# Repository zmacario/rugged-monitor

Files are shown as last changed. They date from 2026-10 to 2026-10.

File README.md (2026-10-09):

# Rugged Monitor EP-0084

A rugged, 3D-printed enclosure for the
[52Pi EP-0084](https://wiki.52pi.com/index.php/EP-0084) 7" capacitive touch display
(1024×600, HDMI, touch over USB).

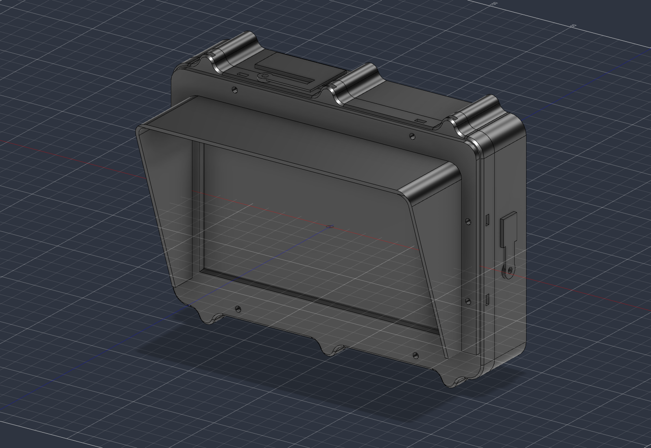
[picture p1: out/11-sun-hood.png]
Front with the sun hood

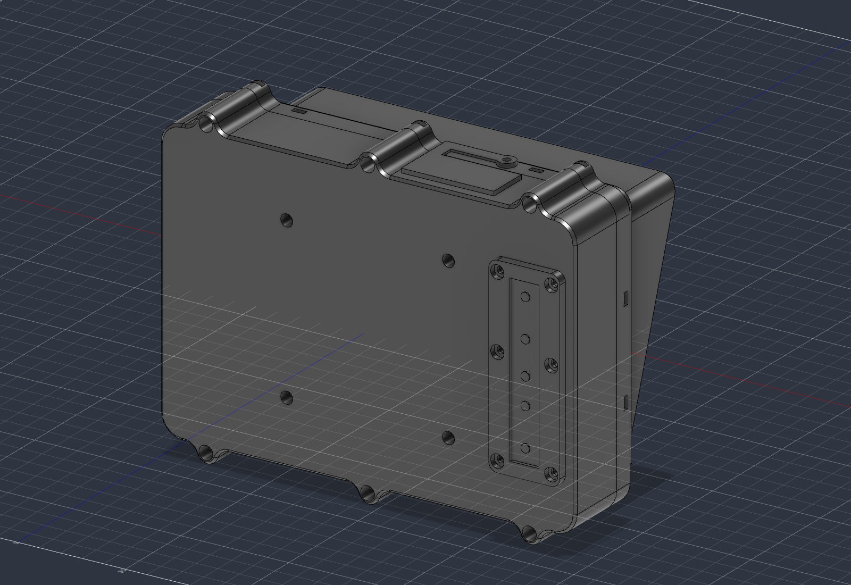
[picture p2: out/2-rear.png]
Rear


- Outer dimensions: 192.9 × 148.9 × 40.5 mm
- VESA 75 mount
- Protection against shock, dust and splashes (gasket between bezel and cover, caps on the ports)
- HDMI and power on the top edge, touch micro-USB on the side
- Menu buttons reachable from outside, through TPU keys
- Detachable sun hood, for use on a car dashboard
- Tilting desk stand, 0° to 60° back from vertical (see [Desk stand](#desk-stand))

## Parts

The files in `out/` open in print orientation and need no supports.

| File | Material | Volume |
|---|---|---|
| `front-bezel.stl` | Rigid | 90 cm³ |
| `chassis.stl` | Rigid | 46 cm³ |
| `rear-cover.stl` | Rigid | 184 cm³ |
| `keypad-frame.stl` | Rigid | 7 cm³ |
| `sun-hood.stl` | Rigid | 42 cm³ |
| `keypad-strip-tpu.stl` | TPU 95A | 2 cm³ |
| `port-cap-hdmi-dc-tpu.stl` | TPU 95A | 4 cm³ |
| `port-cap-usb-tpu.stl` | TPU 95A | 1 cm³ |

Rigid material: ASA for use in a car (PETG softens near 80 °C and PLA is not
suitable); PETG is enough for indoor use.

Fit tests, to validate clearances before printing the large parts:
`test-lcd-pocket.stl` (LCD pocket), `test-hardware.stl` (nut slots and holes) and
`test-port-walls.stl` (the port walls of the cover).

`rugged-monitor.step` holds the full assembly, including the kit components as
reference.

## Hardware

| Qty | Part | Where |
|---|---|---|
| 6 | M3×20 screw, socket cap head (DIN 912) | Closing the cover against the bezel |
| 5 | M3×16 screw, button head (ISO 7380) | Key pins |
| 31 | M3×10 screw, button head (ISO 7380) | Chassis (9), boards (6), keypad frame (6), sun hood (6), OSD keypad (2), port cap tethers (2) |
| 29 | M3 hex nut, standard (DIN 934) | Closure (6), chassis (9), boards (6), sun hood (8) |
| 10 | M3 heat-set threaded insert | Keypad frame (6), OSD keypad (2), port cap tethers (2) |
| 4 | M4 heat-set threaded insert | VESA mount |
| 4 | M4×8 screw | VESA mount |
| — | Neutral-cure silicone sealant | Gasket between bezel and cover |
| — | 1 mm adhesive foam tape | Between the front lip and the glass; between the LCD and the chassis |

No screw threads directly into plastic: nuts are held captive in slots where there
is access, and brass inserts are used in the blind holes that must not go through
the wall.

## Assembly, in short

1. Slide the 9 chassis nuts into the slots in the wall of the LCD pocket.
2. Stick the foam on the lip and lay the LCD + glass assembly in, with the flex cables on the side of the stops.
3. Fit the 6 nuts under the chassis, pass the flex cables through its slots and screw the chassis down.
4. Mount the video board and the touch board on the chassis and connect the flex cables.
5. On the cover: set the inserts, drop in the key pins, mount the OSD keypad, the keypad strip and the frame.
6. Close the cover with the 6 M3×20 screws.

The gasket is formed in place: silicone in the bezel groove, release agent on the
cover tongue, cured with the case closed and empty.

## Desk stand

A printed stand to use the monitor on a table. It bolts to the VESA 75 pattern of the
cover, so the enclosure itself is not modified, and the screen tilts from upright to
60° back.

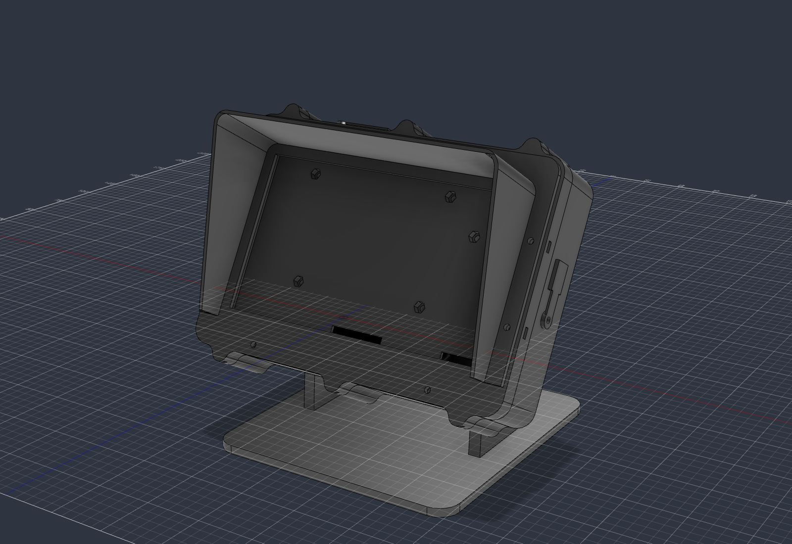
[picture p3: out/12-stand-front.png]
Desk stand, tilted 30°

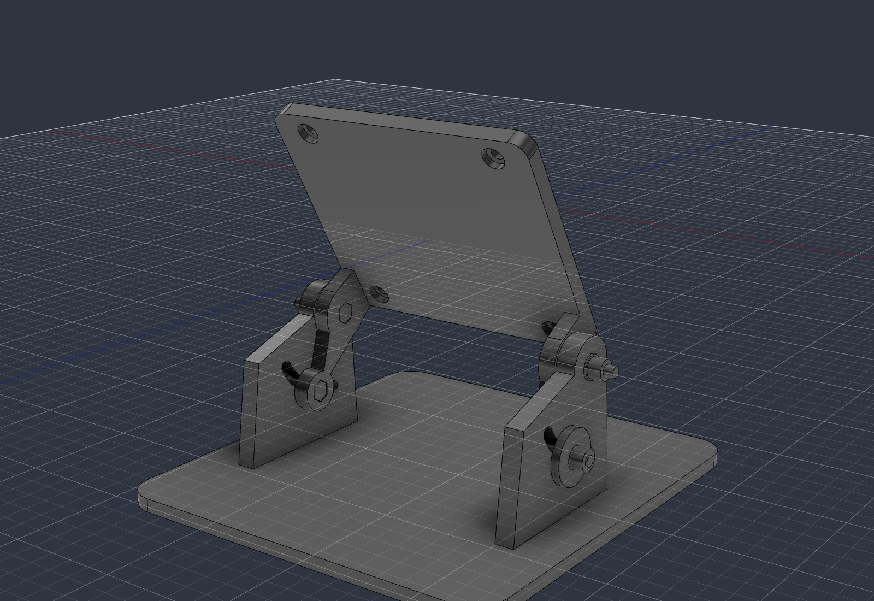
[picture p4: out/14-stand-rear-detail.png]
Stand from behind


- Footprint 150 × 160 mm; the lowest edge of the enclosure is 11 mm above the table
  when upright
- Two printed parts, no supports: a base with two arms, and a bracket (VESA plate with
  two side walls) that turns between the arms
- One M4 bolt per side is the pivot. A second one runs in an arc slot of the arm; a
  wing nut clamps the wall against the arm to hold the angle, so the tilt is
  continuous
- The sun hood fits at every angle; the stand does not cover the ports, the closure
  screws or the keys
- Self-adhesive rubber feet go in the four recesses under the base

| File | Material | Volume |
|---|---|---|
| `stand-base.stl` | Rigid | 153 cm³ |
| `stand-bracket.stl` | Rigid | 62 cm³ |
| `test-stand-hinge.stl` | Rigid | 28 cm³ |

`test-stand-hinge.stl` is a fit test: one arm with its slot and one wall with the
hex pockets and the counterbored VESA hole. Print it before the two large parts.
`desk-stand.step` holds the assembly, with the enclosure tilted 30° as reference.

| Qty | Part | Where |
|---|---|---|
| 4 | M4×8 screw, button head (ISO 7380) | Bracket to the VESA inserts of the cover |
| 4 | M4×20 bolt, hex head (DIN 933) | Pivot (2) and tilt lock (2); the head sits in a hex pocket of the wall |
| 2 | M4 nylon lock nut (DIN 985) | Pivot |
| 2 | M4 wing nut (DIN 315) | Tilt lock |
| 4 | M4 washer, 9 mm outside diameter | Under the nuts |
| 4 | Self-adhesive rubber foot, Ø10 mm | Underside of the base |

Assembly, in short:

1. Screw the bracket to the four VESA inserts of the cover; the screw heads sit in the counterbores.
2. Stand the base up and lower the bracket between its two arms.
3. On each side, push a bolt from inside the bracket through the wall and the arm, with the head in the hex pocket.
4. Pivot: washer and lock nut, tightened until the bracket turns freely without play.
5. Lock: washer and wing nut. Loosen to tilt, tighten to hold.

The two walls sit inside the arms, with 0.6 mm between wall and arm until the wing nut
is tightened.

## Regenerating the model

The model is generated by the `fusion/RuggedMonitor/RuggedMonitor.py` script, for
Autodesk Fusion. Every dimension lives in the `P` dictionary at the top of the file.

1. Copy (or link) the `fusion/RuggedMonitor` folder into Fusion's scripts folder.
2. In Fusion: Utilities → Scripts and Add-Ins → RuggedMonitor → Run.

The script rebuilds the "Rugged Monitor" document if it is open (otherwise it creates
a new one) and writes the STL files, the STEP file and the images to `out/`.

The stand is generated the same way by `fusion/RuggedMonitorStand/RuggedMonitorStand.py`
(link the `fusion/RuggedMonitorStand` folder too). It takes the enclosure from
`RuggedMonitor.py`, so both folders must be in the repository layout. Besides the parts
it moves the enclosure through the whole tilt range and logs any overlap and the
closest approach to the base in `out/build-stand.log`.

## Status

The bezel, chassis and cover have been printed and validated against the real
hardware. The keys (TPU strip, pins and frame), the port caps and the silicone gasket
have not been tested yet.

The desk stand has been checked in the model only (no overlaps from 0° to 60°, hardware
included). It has not been printed yet.

## License

- **The Fusion scripts** (`fusion/RuggedMonitor`, `fusion/RuggedMonitorStand`) — [MIT](LICENSE)
- **The design** (`out/*.step`, `out/*.stl`, renders) — [CC BY-SA 4.0](LICENSE-DESIGN.md)

You may print and sell this enclosure and its stand; credit José Macário (@zmacario), link back here,
and share modifications of the design under the same license. See
[LICENSE-DESIGN.md](LICENSE-DESIGN.md).

Not affiliated with 52Pi.

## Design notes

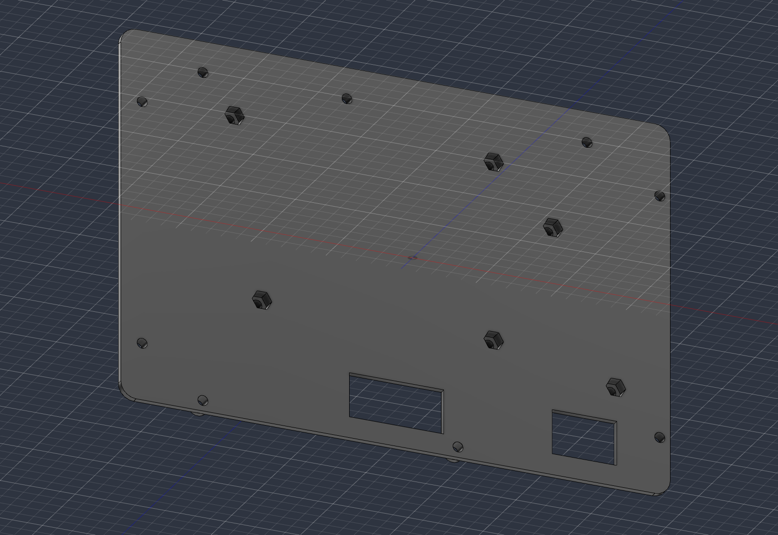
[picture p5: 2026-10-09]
out/10-chassis-underside.png

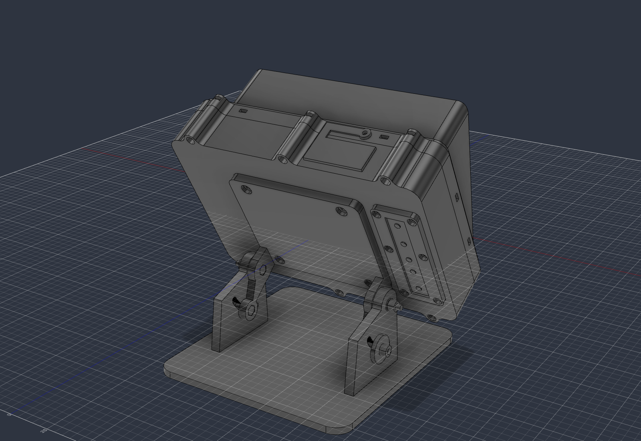
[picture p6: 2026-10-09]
out/13-stand-rear.png

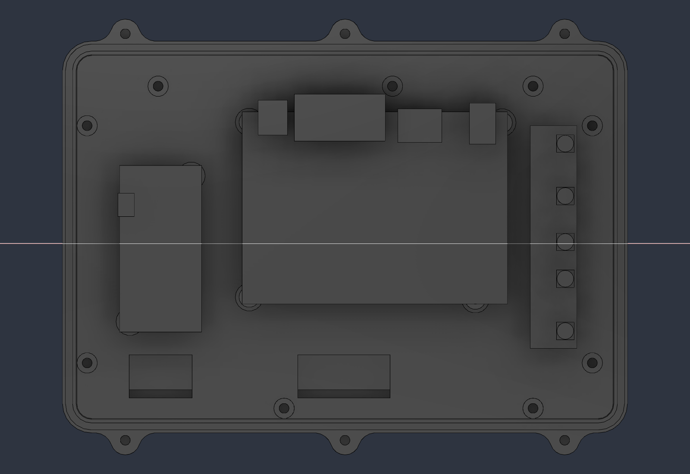
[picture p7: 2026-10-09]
out/4-interior-top.png

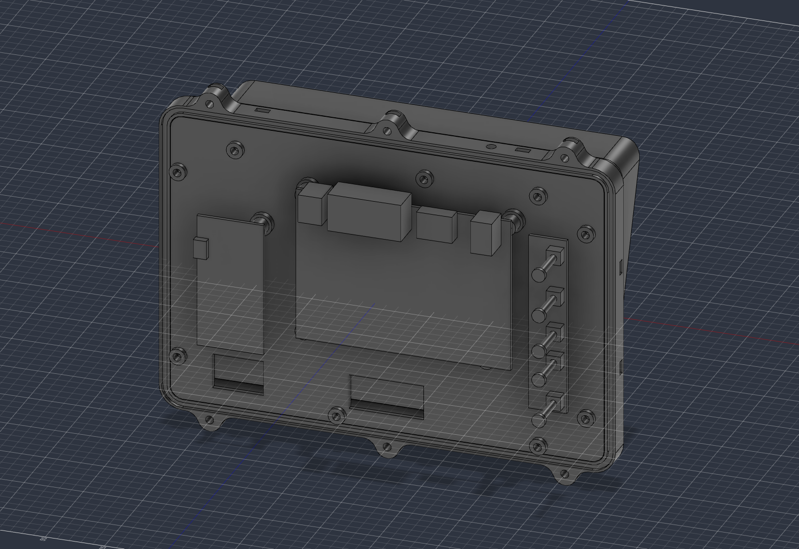
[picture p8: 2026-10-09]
out/3-interior.png

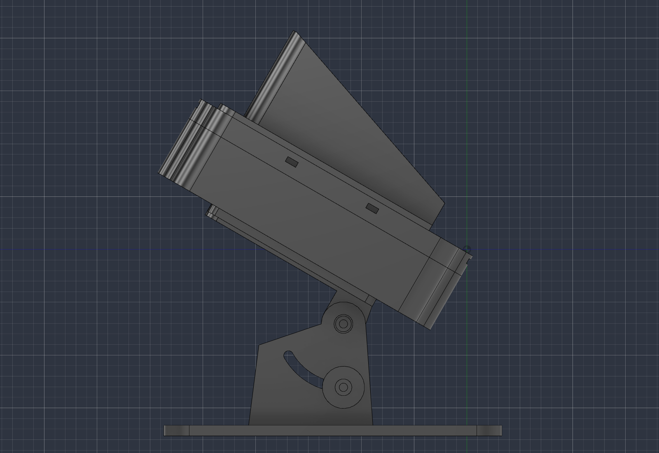
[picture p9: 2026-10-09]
out/15-stand-side-60.png

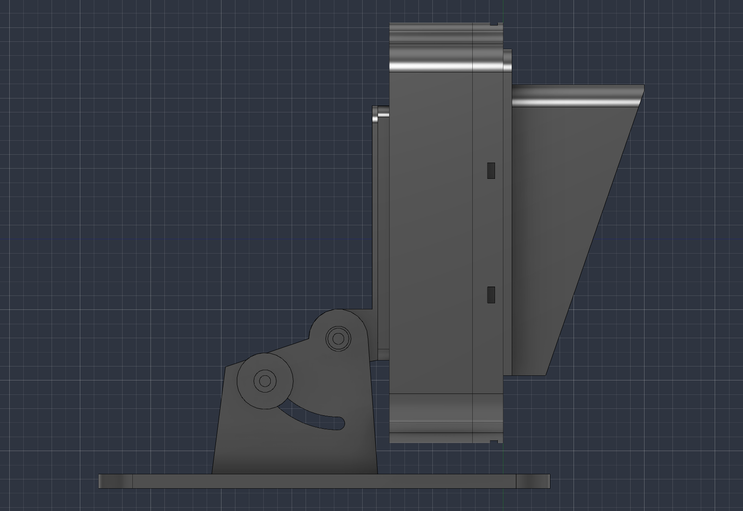
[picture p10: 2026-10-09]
out/15-stand-side-0.png

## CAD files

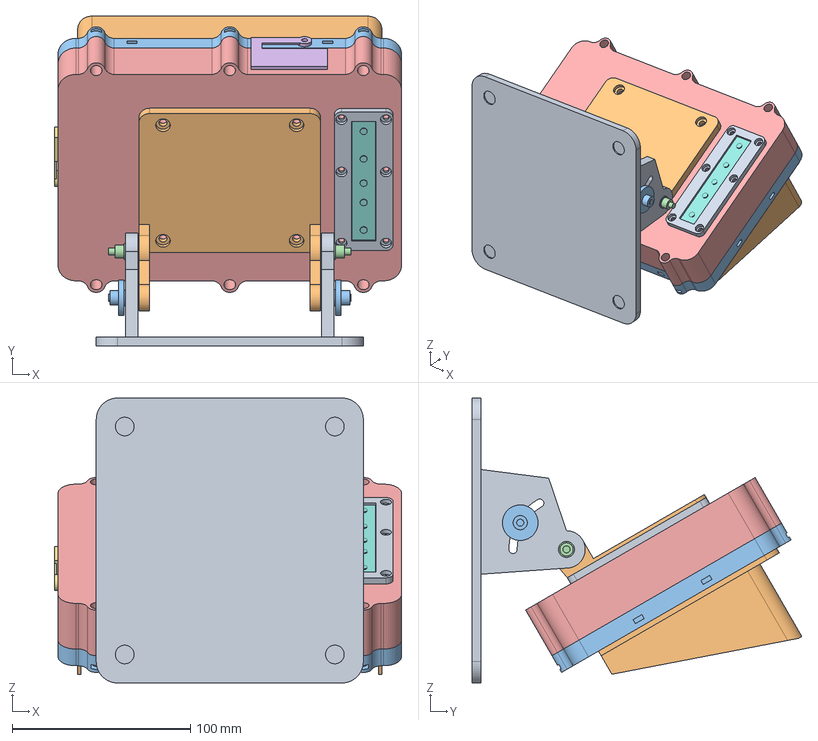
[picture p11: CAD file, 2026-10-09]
out/desk-stand.step
194.9 x 185.2 x 160.0 mm

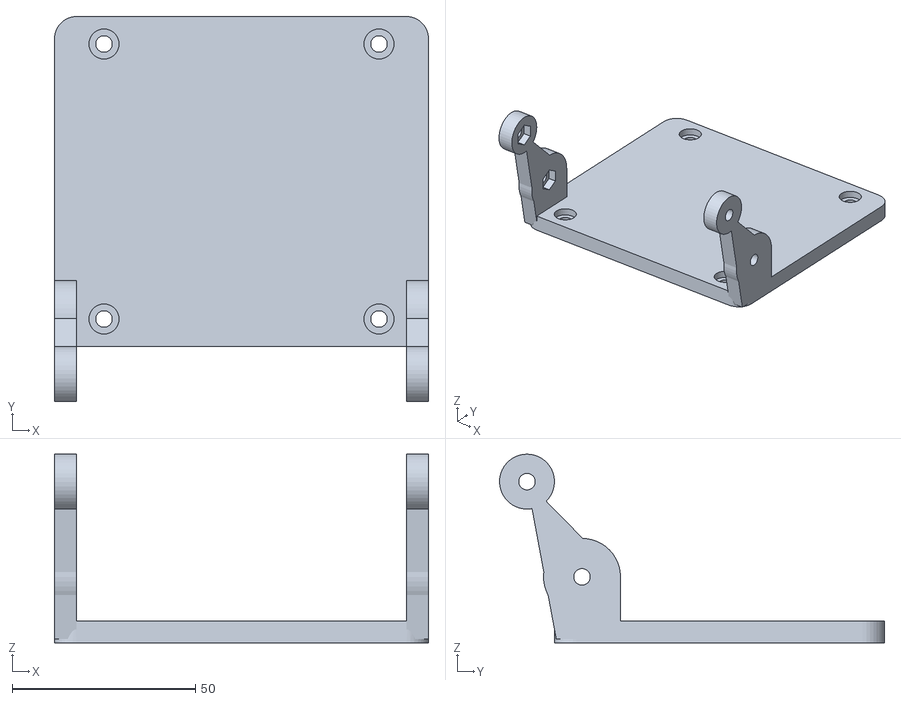
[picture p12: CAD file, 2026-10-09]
out/stand-bracket.stl
102.0 x 105.0 x 51.5

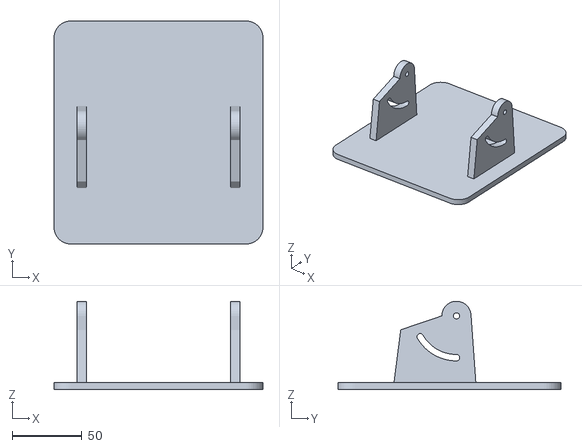
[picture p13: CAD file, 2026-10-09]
out/stand-base.stl
150.0 x 160.0 x 63.5

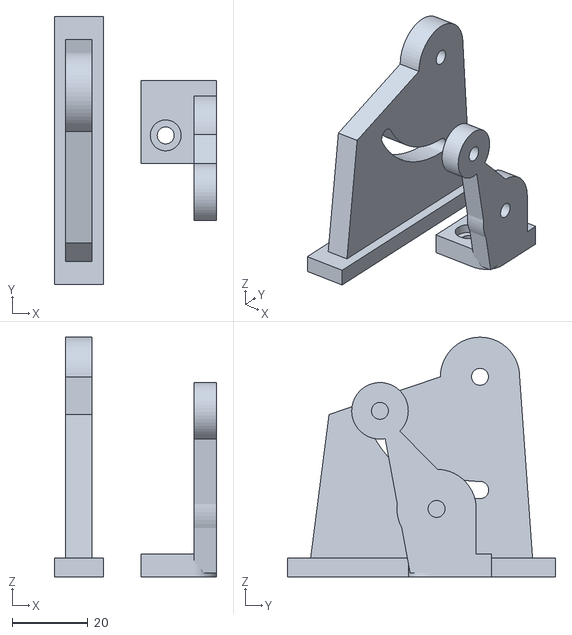
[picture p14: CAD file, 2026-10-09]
out/test-stand-hinge.stl
43.0 x 71.0 x 63.5

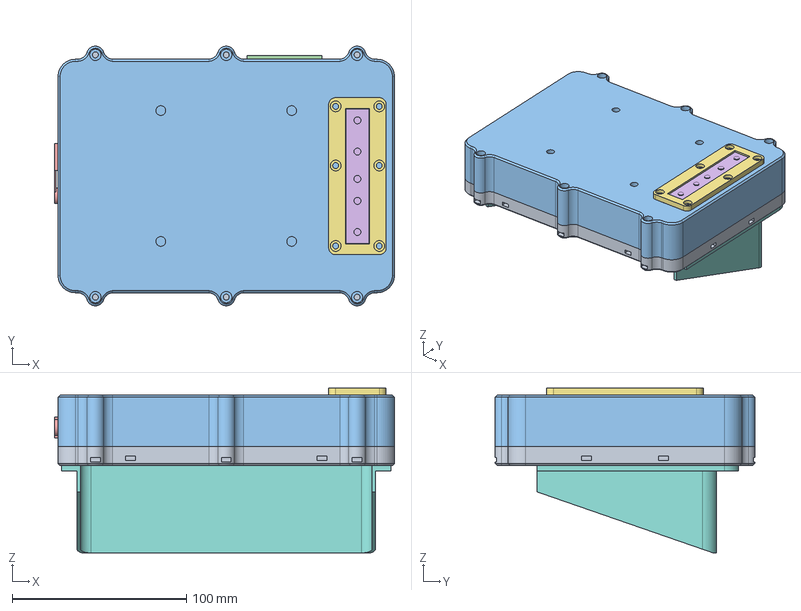
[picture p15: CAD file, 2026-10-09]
out/rugged-monitor.step
194.9 x 148.9 x 94.5 mm

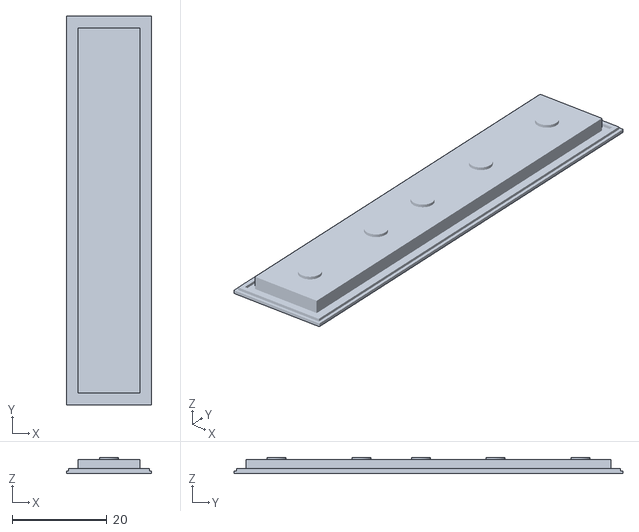
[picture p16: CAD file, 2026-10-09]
out/keypad-strip-tpu.stl
18.0 x 82.0 x 3.45

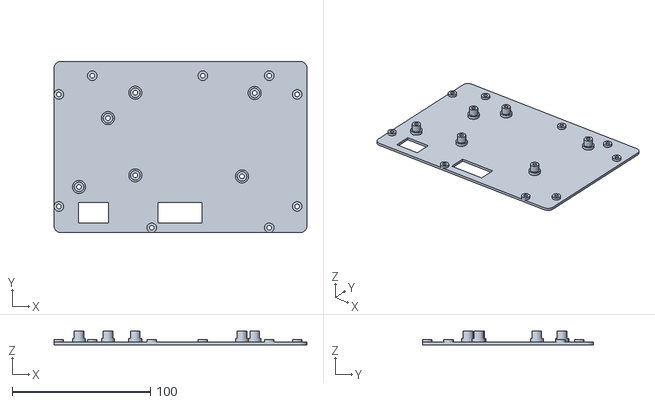
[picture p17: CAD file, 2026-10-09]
out/chassis.stl
183.1 x 124.1 x 10.0

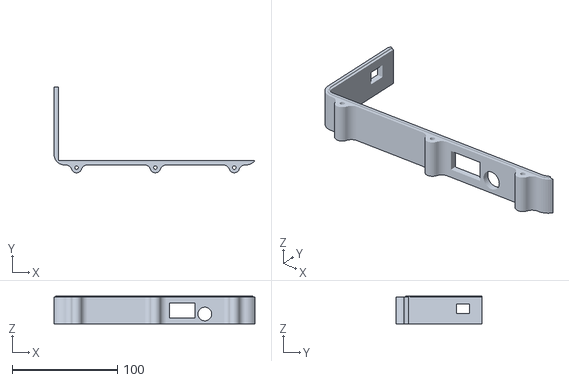
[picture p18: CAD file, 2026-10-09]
out/test-port-walls.stl
191.1 x 81.4 x 26.6

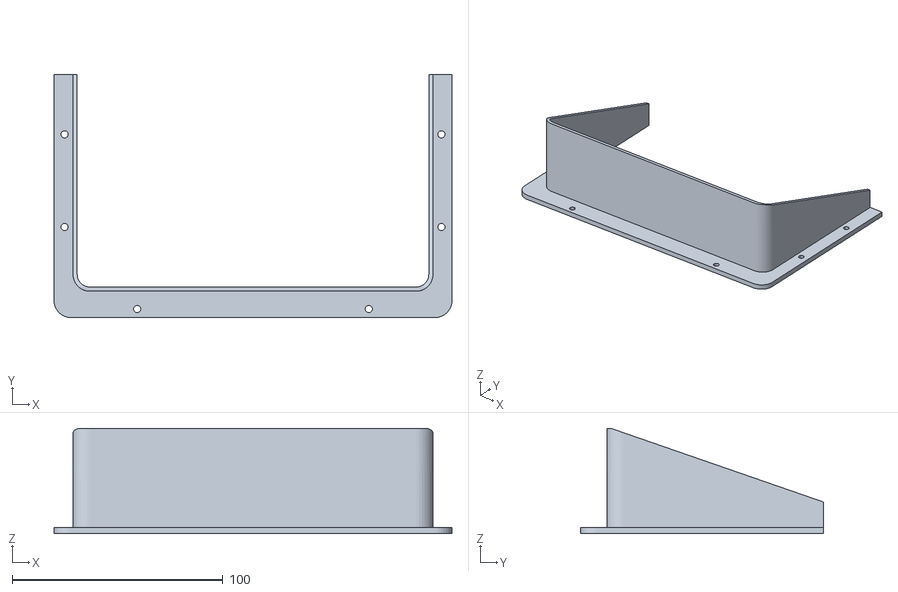
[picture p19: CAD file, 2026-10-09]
out/sun-hood.stl
189.1 x 115.5 x 50.0

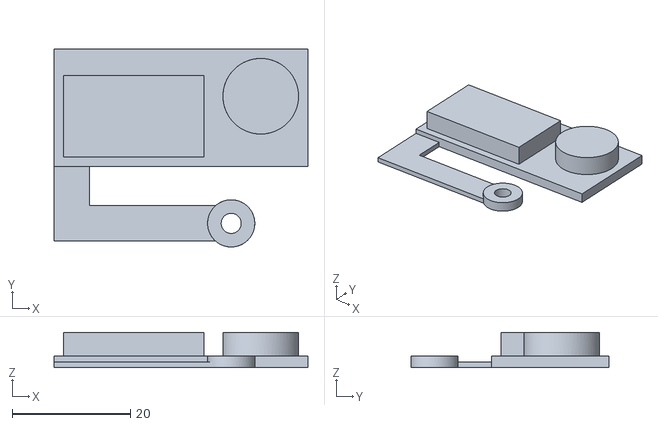
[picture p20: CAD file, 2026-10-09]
out/port-cap-hdmi-dc-tpu.stl
43.0 x 33.5 x 6.00

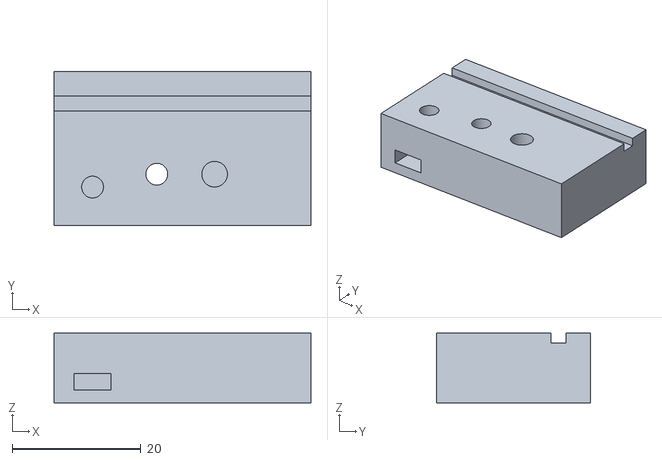
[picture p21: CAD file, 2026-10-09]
out/test-hardware.stl
40.0 x 24.0 x 10.9

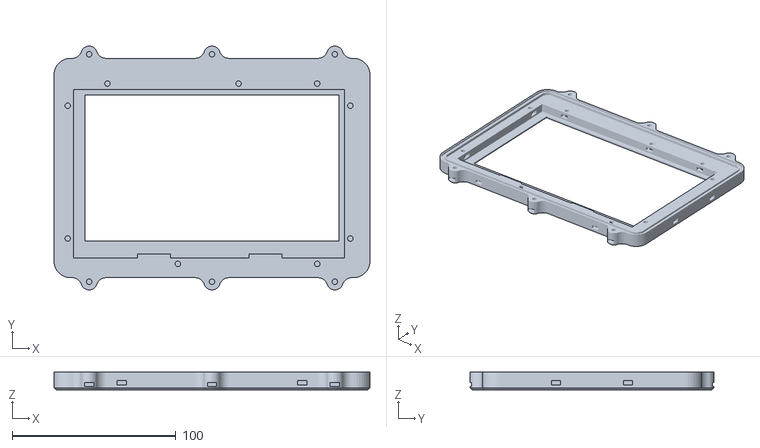
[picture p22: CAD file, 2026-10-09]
out/front-bezel.stl
192.9 x 148.8 x 10.9

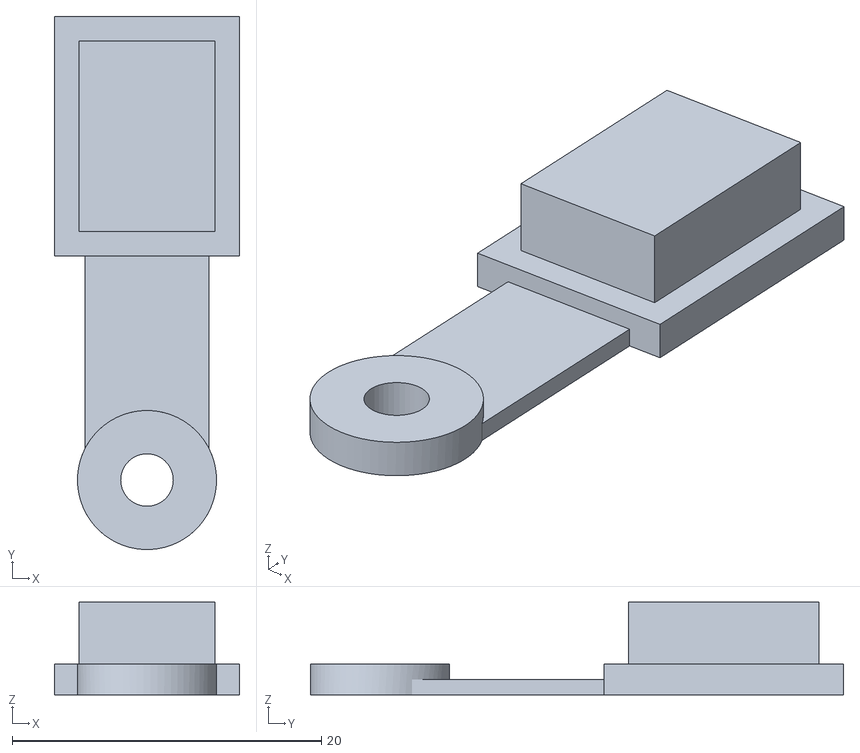
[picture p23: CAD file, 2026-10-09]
out/port-cap-usb-tpu.stl
12.0 x 34.5 x 6.00

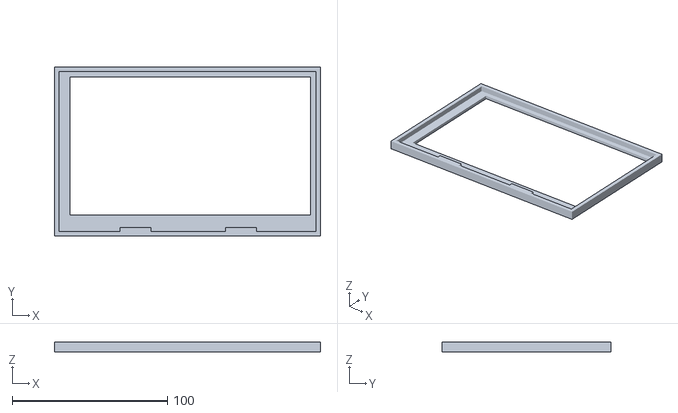
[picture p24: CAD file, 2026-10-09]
out/test-lcd-pocket.stl
171.5 x 109.1 x 6.50

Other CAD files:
out/keypad-frame.stl
out/rear-cover.stl

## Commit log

2026-10-09 Caixa robusta para o ecrã 52Pi EP-0084
    Script do Fusion que gera o modelo, ficheiros STL na posição de impressão,
    STEP do conjunto, imagens e provas de encaixe.
    [aro-teclas.stl, chassis.stl, moldura-frontal.stl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]
2026-10-09 Translate the project to English
    Component names, output file names, log messages, script comments and the
    README are now in US English. Geometry is unchanged.
    [front-bezel.stl, keypad-frame.stl, keypad-strip-tpu.stl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]
2026-10-09 Add a tilting desk stand
    Two printed parts, a base with two arms and a bracket that bolts to the
    VESA 75 inserts of the rear cover, tilt the screen from upright to 60 degrees
    back. An M4 pivot per side and a second bolt in an arc slot hold the angle.
    The new Fusion script builds the stand around the enclosure from
    RuggedMonitor.py and moves it through the whole tilt range, logging overlaps
    and clearances. RuggedMonitor.py now also reports the VESA centre in X.
    Includes a hinge fit test, the STEP assembly and renders.
    [desk-stand.step, stand-base.stl, stand-bracket.stl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]
2026-10-13 Widen the walls of the stand bracket
    The web between the pivot and the lock bolt was about 9 mm wide, too
    narrow for a printed part. The wall is now the convex hull of the two
    bosses (at least 18 mm wide), the lock boss grows from 7.5 to 9 mm in
    radius and the wall from 6 to 7 mm in thickness.
    The tilt sweep now reports the bracket clearance to the table instead of
    the constant wall-to-arm gap.
2026-10-16 Make the sun hood 30 mm deep and brace its roof
    A 50 mm hood got in the way of touching the top of the screen. The roof is
    now 30 mm deep (the side wings still taper to 15 mm at the bottom), and two
    triangular braces on top tie it to the flange between the two top screws.
2026-10-16 Turn the stand bracket walls into gussets on the plate
    Each wall now runs 45 mm up the edge of the VESA plate and slopes down to the
    pivot boss, so it meets the plate as a gusset instead of a right-angled step.
    The bracket grows from 67 to 74 cm3 and the hinge fit test from 31 to 32 cm3.
2026-10-16 Regenerate the stand renders with the 30 mm sun hood
    The stand assembly and its images still showed the old 50 mm hood. The stand
    parts themselves are unchanged, and the tilt sweep still finds no overlap
    from 0 to 60 degrees.
